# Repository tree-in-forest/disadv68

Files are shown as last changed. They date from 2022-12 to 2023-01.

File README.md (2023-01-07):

# Disadv68 keyboard

This keyboard is a fork of [dactyl-cc](https://github.com/adereth/dactyl-keyboard).

The prototype:
kb_left

Differences with *dactyl-cc* and some notes:

- Fixed switch hole sizes (if you print the current version of *dactly-cc*, you will have a bad time).
- Fixed screw hole sizes for M3 screws and "threaded brass insert" ([AliExpress](https://www.aliexpress.com/item/1005004870993068.htm)).
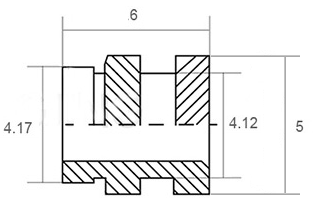
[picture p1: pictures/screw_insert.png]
nut
    

- Original [Kinesis Contoured](https://deskthority.net/wiki/Kinesis_Contoured) keycaps are from ABS and are very expensive (50EUR + shipping).
  *Solution* (use OEM and DSA keycaps). Due to different naming conventions for numbering rows, we will define them as
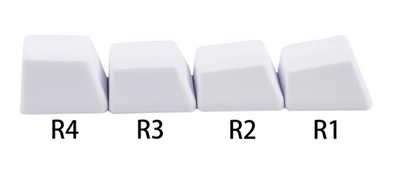
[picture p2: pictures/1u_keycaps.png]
1u
    

  Here is a list of which keycaps you will need (ABS for < 10EUR, PBT < 20EUR):
  - 18 pcs of `1x1u` OEM `R1` (`ZXCV` row),
  - 2  pcs of `2x1u` vertical OEM `R1` (≡ `Numpad Enter` keycap),
  - 2  pcs of `1x2u` horizontal OEM `R1` (≡ `Numpad 0` keycap).
  - 10 pcs of `1x1u` OEM `R2` (`ASDF` row),
  - 12 pcs of `1x1u` OEM `R3` (`QWER` row),
  - 12 pcs of `1x1u` OEM `R4` (`1234` row),
  - 4  pcs of `1x1u` OEM `R5` (`F1F2F3F4` row),
  - 8  pcs of `1x1u` DSA with the deep dish ("blind" keycaps) — you can replace DSA keycaps with `1x1u` OEM `R2` keycaps.
  
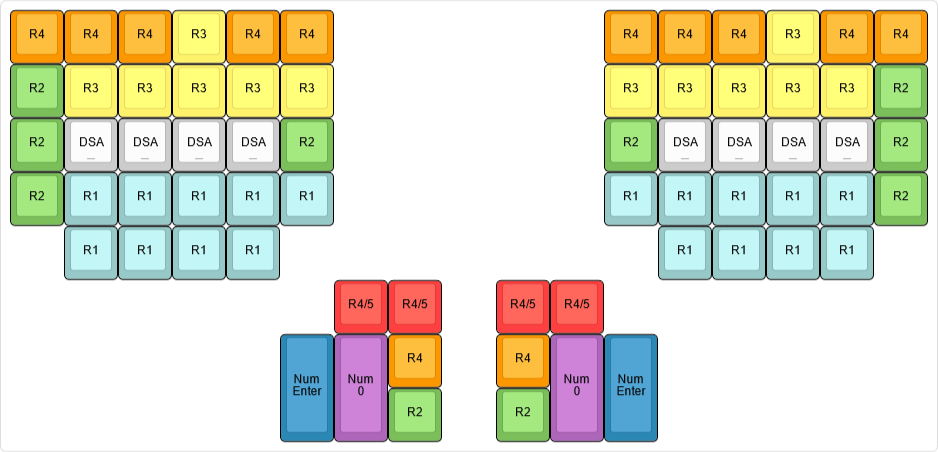
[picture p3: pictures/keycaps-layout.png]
keycaps
  

  The `1u` OEM `R5` keycaps are very rare, so we opted for `R4` keycaps instead. To compensate keycap height difference, we raised the switch sockets/holes by 3mm.
  The `1x1.25u` OEM `R2`s are also very rare so we opted out for `1u` keycaps.
  Note that Cherry stems are not "fully symmetric", therefore if you want to rotate the keycap by 90°, you also need to rotate the switch:

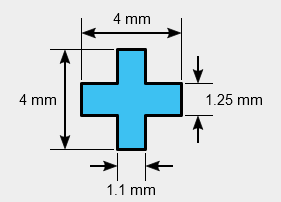
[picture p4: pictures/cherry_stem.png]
stem
  
  
  Sometimes `Numpad Enter` keycaps have rotated stems (therefore, on the standard keyboard the key switch will be placed sideways). Consult with your keycaps vendor if this is the case (it was in ours). This is important because switch sockets have side nubs.
  The current version of the keyboard hull has both sockets with `Numpad Enter` and `Numpad 0` keycaps rotated.

  The other option is to 3D print keycaps. We were unsuccessful in FDM printing — it is hard to get the keycap stems right. Probably the best option is to use [stereolithography](https://en.wikipedia.org/wiki/Stereolithography). If you want to generate the 3D models we suggest you look at the [Parametric Mechanical Keycap Library](https://github.com/rsheldiii/KeyV2).

## FDM printing settings

- Machine Type: Creator 3 Pro
- Material: ASA
- Layer Height: 0.1mm
- Shell Count: 3
- Fill Density: 25%
- Fill Pattern: Hexagon
- Print Speed: 50mm/s
- Travel Speed: 80mm/s
- Extruder Temperature: 250°C
- Platform Temperature: 110°C
- First layer: 0.3mm
- Raft: yes

Due to the long printing time — 50 hours for each side and the small nozzle size, it is very likely that the extruder will get clogged.

## Building STL files

1. Apply your modification to the code. Here are the labels of the key sockets used in the code:
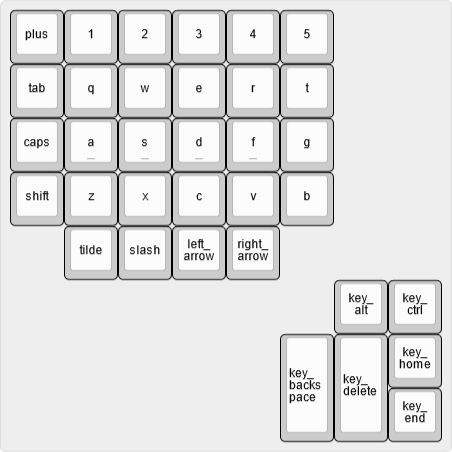
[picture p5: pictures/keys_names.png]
keys_names
   

2. Compile ("requires" CMake).

    ```bash
    cd build
    ./build.sh
    ```

3. Install [OpenSCAD](https://openscad.org/downloads.html) (*Development Snapshot* is the best choice). Files `.scad` will be generated in the folder `build`.

4. Generate STL files.

For measuring distances on STL files we recommend [Blender](https://www.blender.org/).
For post-processing and quick edits, we recommend [Thinkercad](https://www.tinkercad.com).

## Assembly and firmware

Our choice for the microcontroller is `WeAct BlackPill STM32F411CEU6`:

- [QMK docs on blacpill](https://docs.qmk.fm/#/platformdev_blackpill_f4x1?id=weact-blackpill-stm32f4x1)
- [WeAct Studio's blackpill repository](https://github.com/WeActStudio/WeActStudio.MiniSTM32F4x1)

In the folder `things` you can find some custom STLs:

- Custom bottom plate with recesses for USB cable and 12-wire ribbon cable, and modified holes for M3 flat/countersunk head screws.

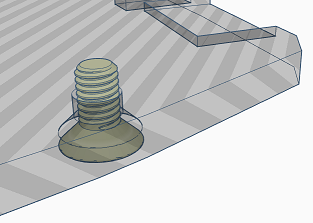
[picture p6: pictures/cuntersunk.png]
screw_hole
  

- A case for blackpill microcontroller.
  
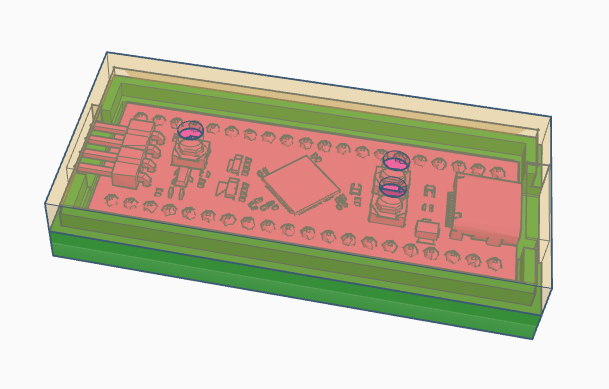
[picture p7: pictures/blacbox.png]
box
  

Note. With low RPM you can easily drill into ASA material.

### What do you need

- 2m of an old hard UTP cable (0 EUR)
- an old floppy drive ribbon cable (or any other ribbon cable, 0EUR)
- 10 pcs of 6mm M3 flat/countersunk/Philips head screws (0.5EUR)
- 10 pcs threaded brass insert (1EUR from Aliexpress)
- keycaps (<10EUR for ABS, <20EUR for PBT on Aliexress — contact the store)
- 68 pcs cherry-like key switches. We have bought 110 Gateron Pro Yellow V2 2.0 for 18EUR (good build quality, linear, pre-lubed).
- WeAct BlackPill STM32F411CEU6 ([where to buy](https://github.com/WeActStudio/WeActStudio.MiniSTM32F4x1#legitimate-purchase-links-as-well-as-pirated-links) 7EUR)
- 24-pin female header for the microcontroller
- 100 1N4148 diodes (0.75EUR)
- Soldering iron with adjustable temperature (borrow, otherwise We recommend [PINEICL](https://pine64.com/product/pinecil-smart-mini-portable-soldering-iron/) or a cheap one on Aliexpress)
- Solder
- Tweezers with a tiny head
- Wirecutter
- Razor knife
- Scissors pliers for wire stripping (that support small wires)
- USB-C cable
- Multimeter
- Hot glue gun
- Around 25 hours of spare time
- ...

### Assembly

1. Clean up/remove support from the printed hull.
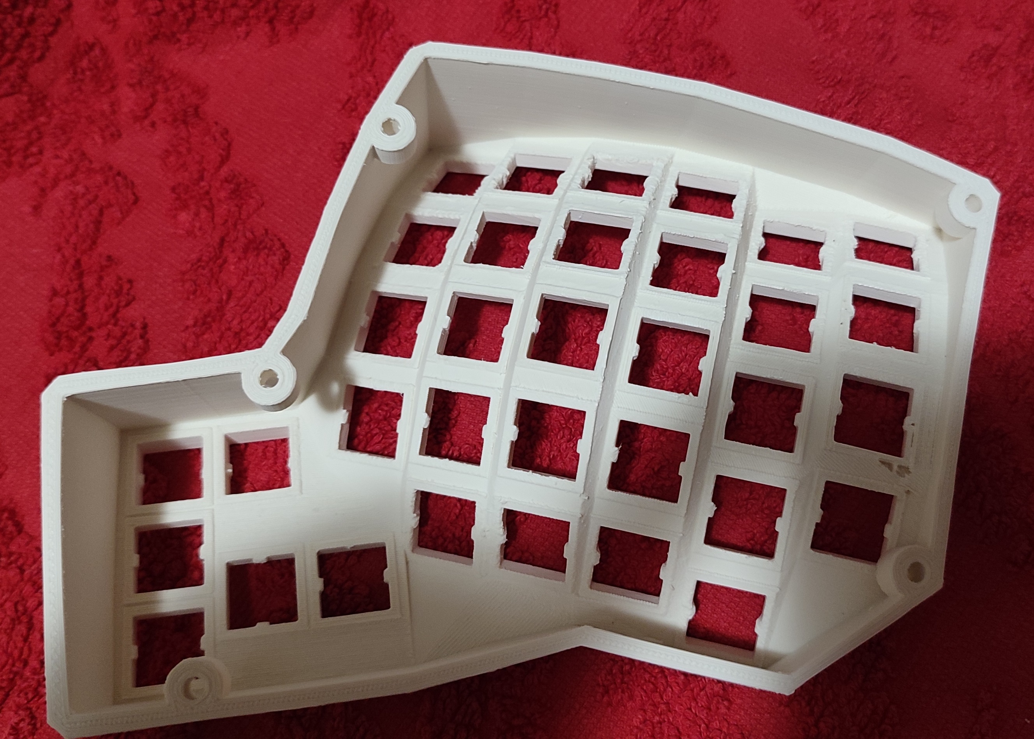
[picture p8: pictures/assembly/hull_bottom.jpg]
hull1
   
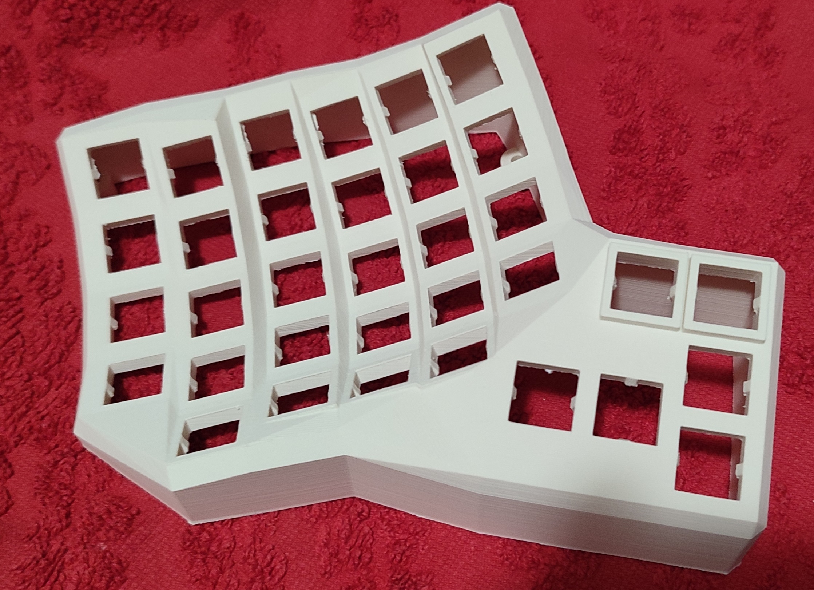
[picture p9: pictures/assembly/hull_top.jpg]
hull2
   

2. Add switches and keycaps
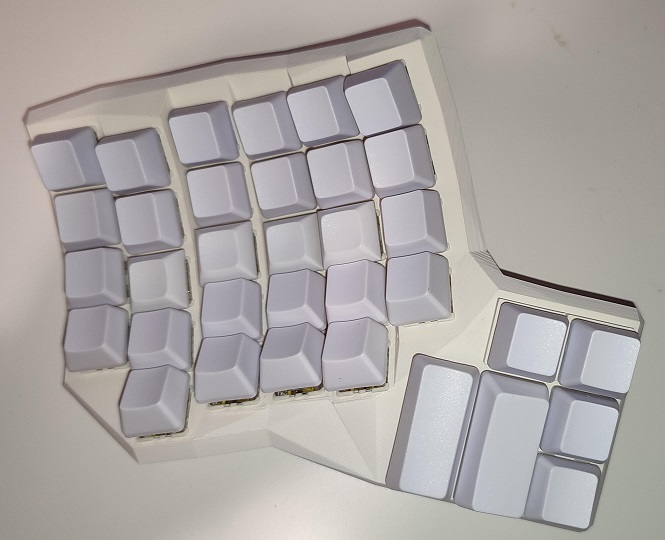
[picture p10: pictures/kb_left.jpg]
left
   

3. Stabilize switches with hot glue.

4. Place wires for the columns (if you start with rows first, it is harder to replace diodes/switches later).

     - Extract/unwind wires from the UTP cable
     - Make a hook.
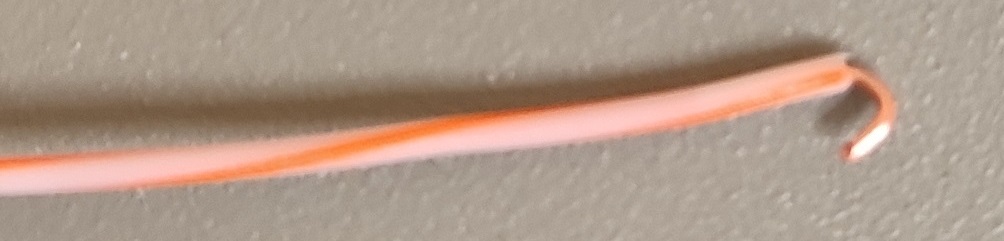
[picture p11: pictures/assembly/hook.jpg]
hook
        
     - Hook up the wire to the top row pin and mark the position for the rest of the pins.
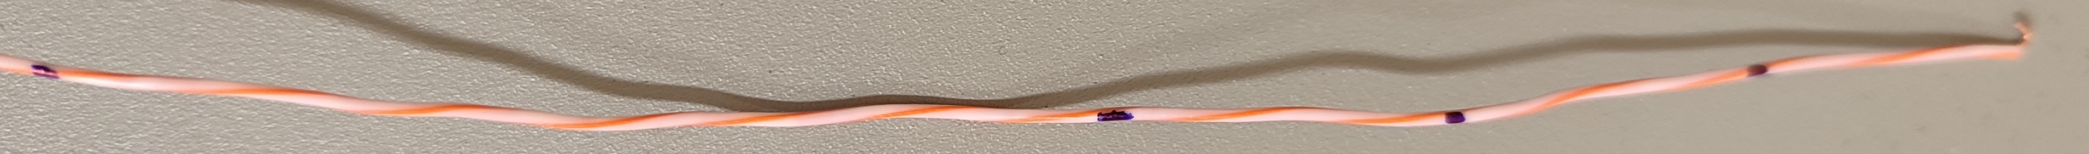
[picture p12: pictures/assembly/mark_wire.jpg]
marks
       
     - Using the scissors pliers for wire stripping cut the insulator for each mark twice. Then use a Razor knife to partially peel off the insulator.
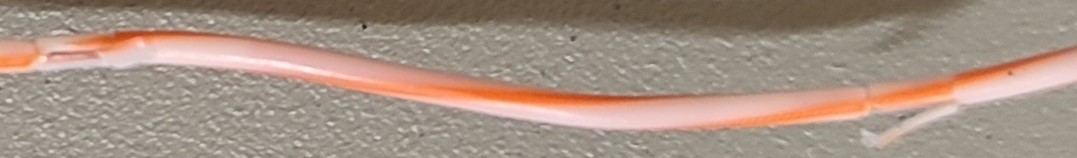
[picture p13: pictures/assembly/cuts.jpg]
cuts
     
     - Remove the rest of the insulator using tweezers.
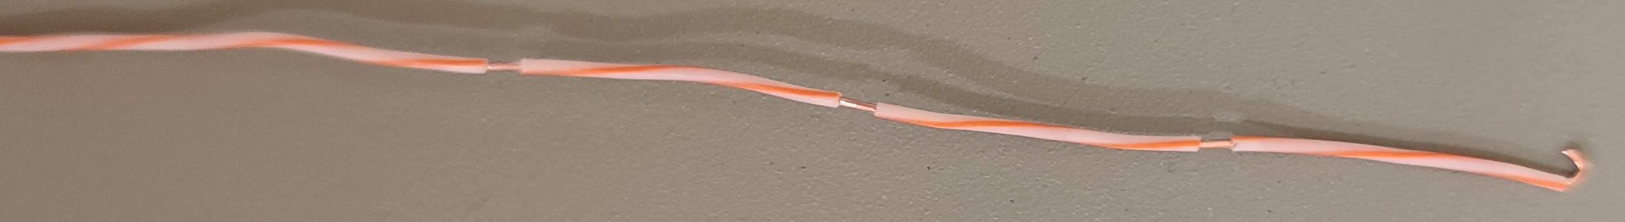
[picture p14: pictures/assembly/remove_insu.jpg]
remove
     
     - Apply flux and solder the column wires to the switch pins.
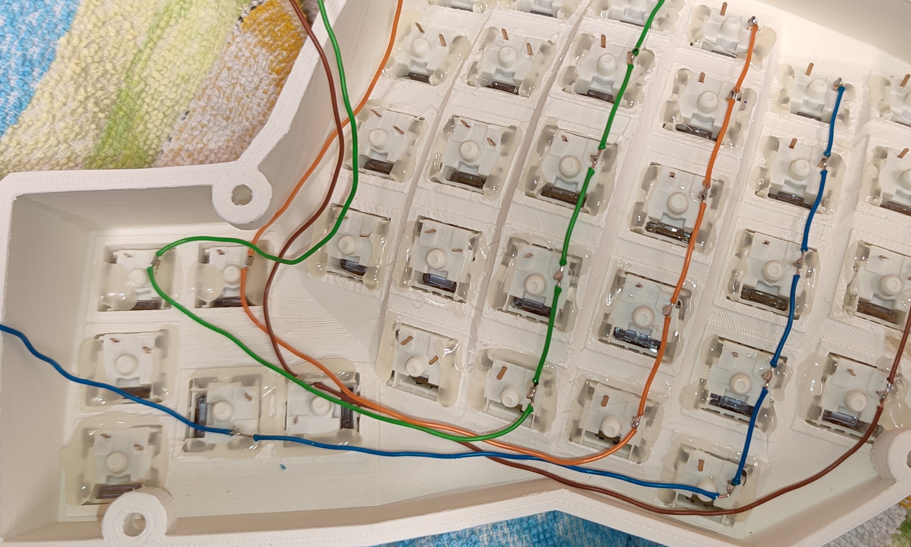
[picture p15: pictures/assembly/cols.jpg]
cols
     

5. Make rows from diodes (start with making "eyes") — double-check the orientation of diodes.
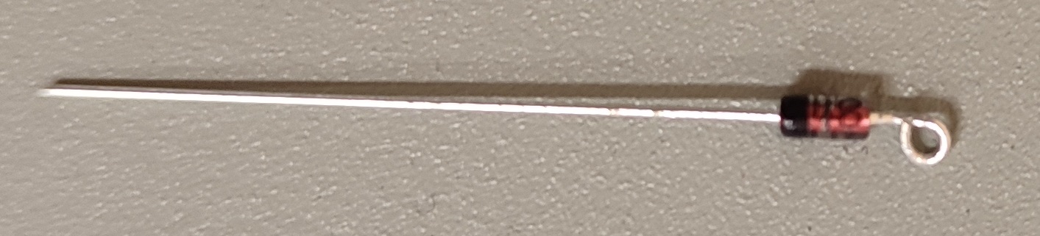
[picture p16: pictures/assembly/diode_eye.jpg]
eye
     
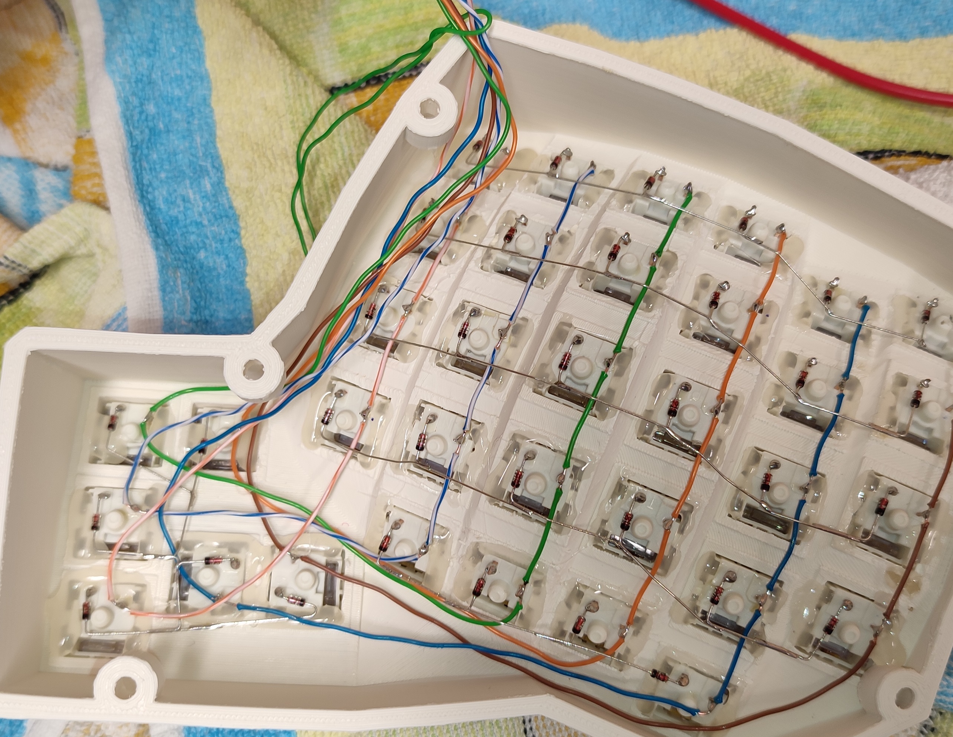
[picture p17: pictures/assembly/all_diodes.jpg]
all_diodes
     

6. Connect wires to the female header for the microcontroller.
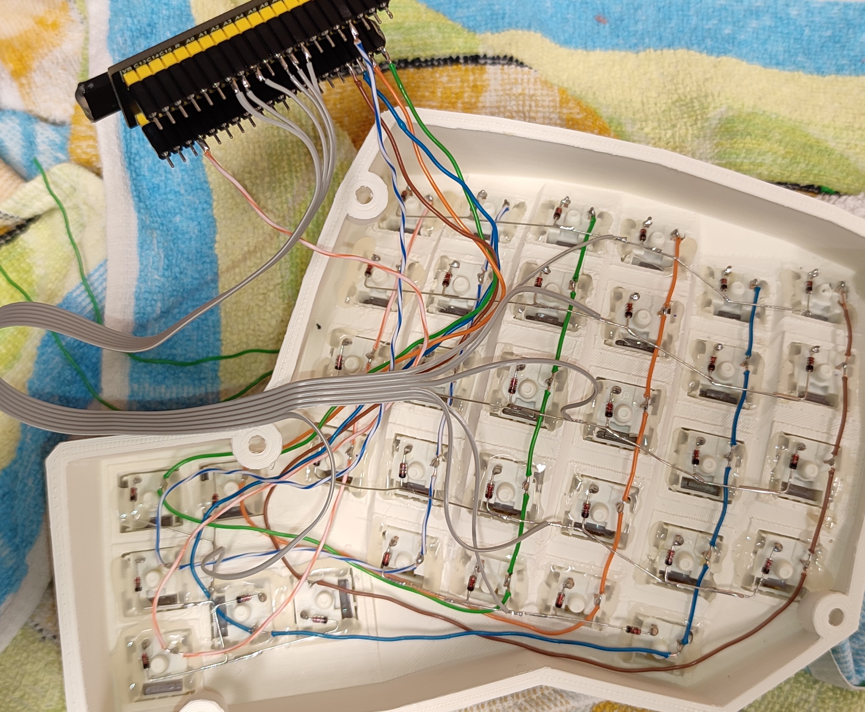
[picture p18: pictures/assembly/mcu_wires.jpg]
mcu_wires
  

7. Test the left side of the keyboard (flash the microcontroller first).
8. Make the right side.
9. Insert screw inserts slowly using soldering iron at 200°C.
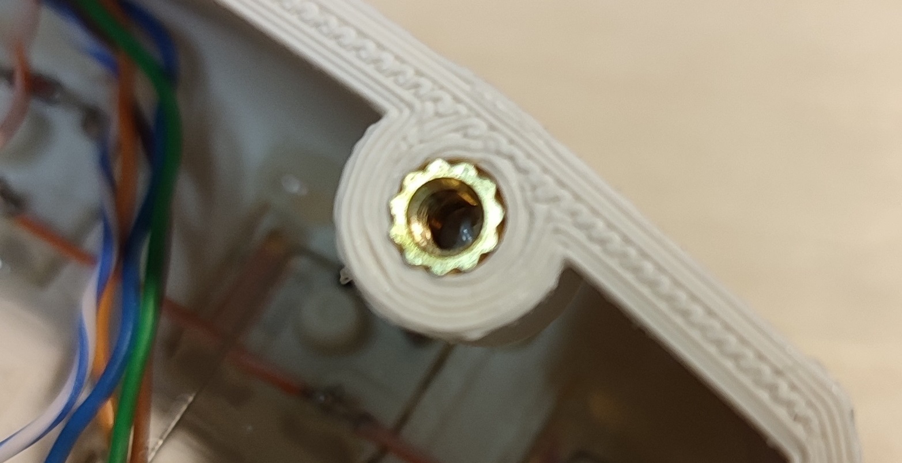
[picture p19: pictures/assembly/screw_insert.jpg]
screw_inserts
  
10. Connect the left and the right side with a 12-wire ribbon (6 columns and 6 rows) cable according to your firmware settings.
11. Connect [USB wires](https://en.wikipedia.org/wiki/USB_hardware) to the female header for the microcontroller (`D-` → `A11`, `D+` → `A12`, `+5V` → `5V`, and `GND` → `G`). This will reduce the footprint of the microcontroller inside the keyboard hull.
12. Secure the wires with hot glue.
13. Make the bottom plates. Our 3D printer had problems. So we used 4mm plywood with longer (8mm) M3 screws. Here is the design for the wooden bottom plate — [bottom_left](things/custom_bottom_plate/bottom_left.svg) and [bottom_right](things/custom_bottom_plate/bottom_right.svg). These designs do not take into account the ASA shrinkages. You need to do modifications on your own.
14. Use M3 screws to secure the bottom plates
15. Add pads to the bottom plates (you can make them from an old mousepad).
16. Walla, you should have a functional keyboard now.
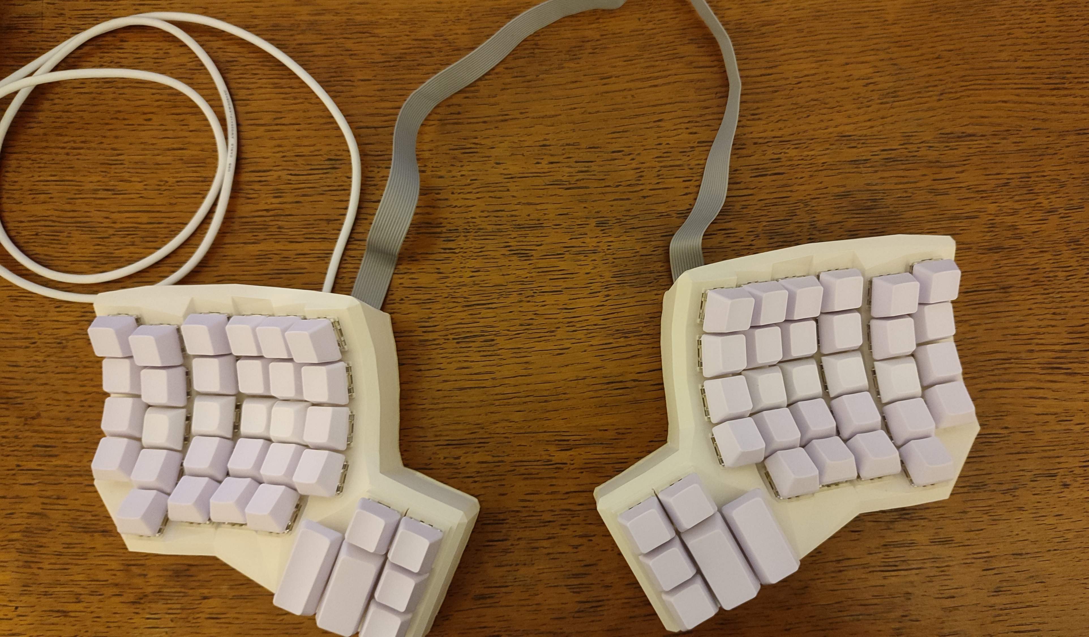
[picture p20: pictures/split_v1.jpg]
v1
   

### Firmware

...can be found [here — qmk_firmware](https://github.com/tree-in-forest/qmk_firmware/tree/disadv68/keyboards/handwired/disadv68).

### Layout

The default layout is:

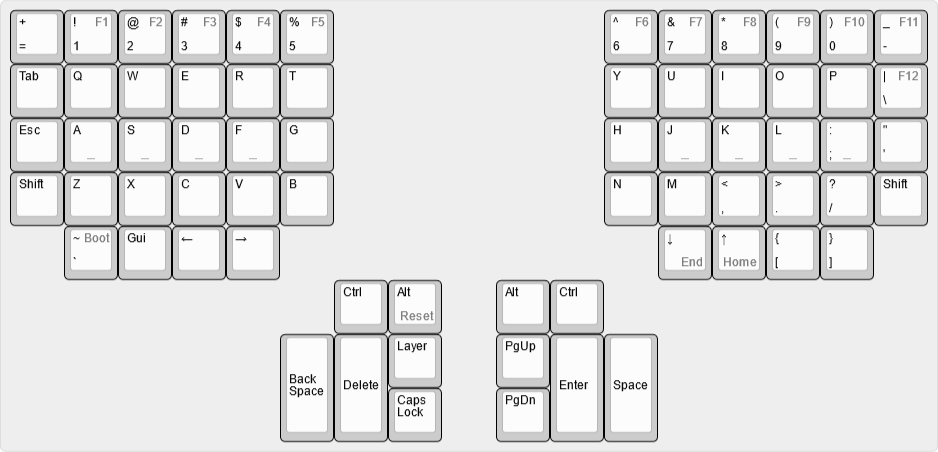
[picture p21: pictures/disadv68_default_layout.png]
default_layout


- To access F-keys use the Layer key.
- Reset the keyboard: `Layer + RAlt`
- Jump to the bootloader ``Layer + ` ``

Nice layouts to check out:

- [The Hands Down™ Layout](https://sites.google.com/alanreiser.com/handsdown)

## Traveling case

Coming soon.

## Wrist rests

Coming soon.

## Adjustable tilting supports

Coming soon.

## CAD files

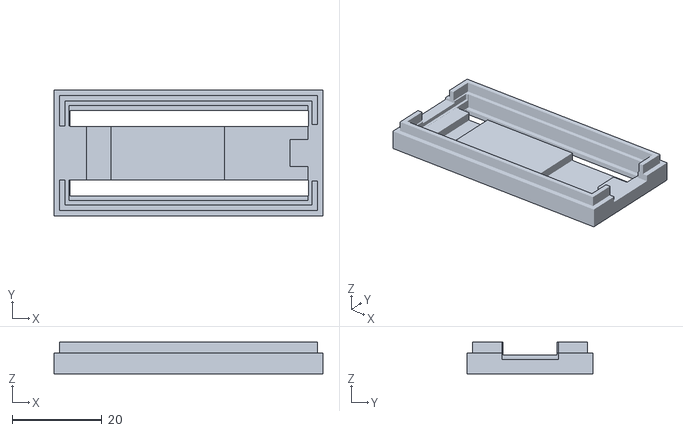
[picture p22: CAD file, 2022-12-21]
things/blacbox/blackbox_bottom.stl
60.0 x 28.0 x 7.10

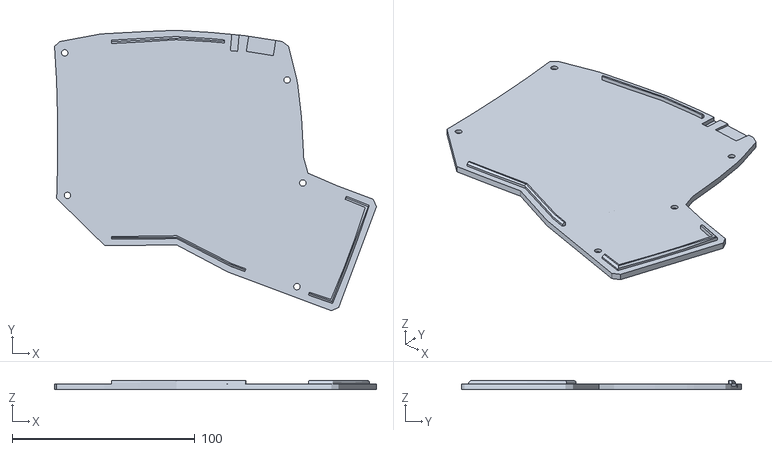
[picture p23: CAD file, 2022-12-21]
things/custom_bottom_plate/custom_bottom_plate_left.stl
176.2 x 153.4 x 5.00

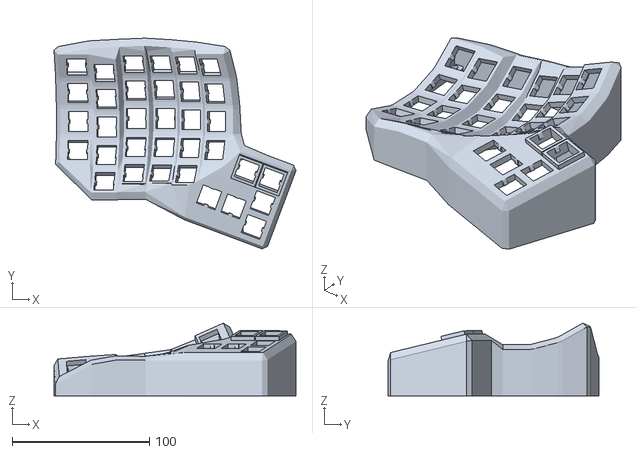
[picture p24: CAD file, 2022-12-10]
things/left.stl
176.2 x 153.4 x 53.0

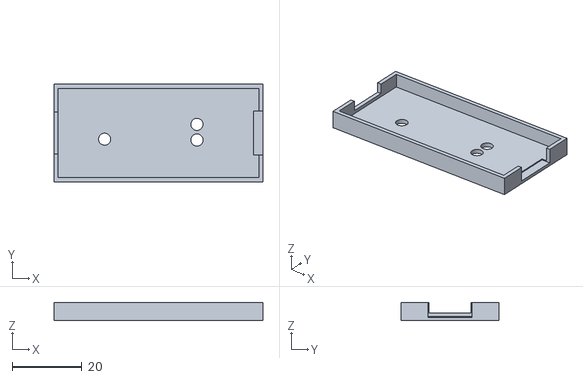
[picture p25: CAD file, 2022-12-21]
things/blacbox/blackbox_top.stl
60.0 x 28.0 x 5.20

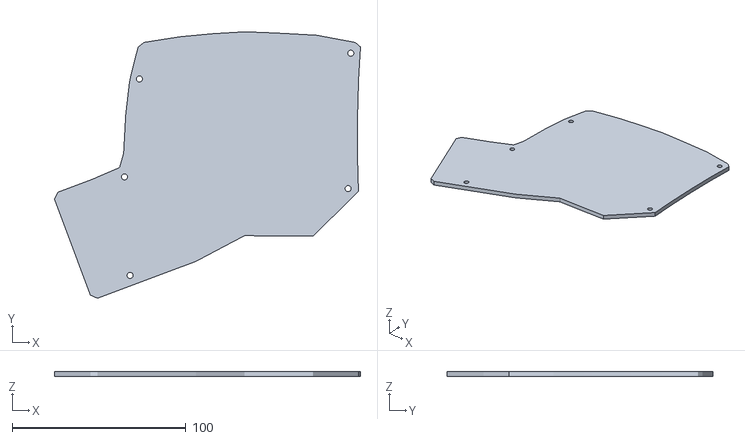
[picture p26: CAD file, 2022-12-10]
things/bottom_right.stl
176.2 x 153.4 x 3.00

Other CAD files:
things/custom_bottom_plate/custom_bottom_plate_right.stl
things/bottom_left.stl
things/right.stl

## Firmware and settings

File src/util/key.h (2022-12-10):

#pragma once

#include <functional>
#include <glm/glm.hpp>
#include <memory>
#include <string>

#include "scad.h"
#include "transform.h"

namespace scad {

// All sizes in mm.
const double kSwitchWidth = 14.4;
const double kSwitchThickness = 4;
const double kWallWidth = 2;

const double kDsaHeight = 8;
const double kSaHeight = 12.5;
// This is the height of the taller side on the key. The short side has kSaHeight.
const double kSaEdgeHeight = 13.7;
const double kDsaTopSize = 13.2;     // 0.5 * kMmPerInch;
const double kDsaBottomSize = 18.4;  // 0.725 * kMmPerInch;
// The size half way up the key used to generate the cap shape.
const double kDsaHalfSize = 16.2;
const double kSaHalfSize = 17.2;

// Size for the tall sa edged key.
const double kSaTallHeight = 14;
const double kSaTallEdgeHeight = 16.5;

const double kSwitchHorizontalOffset = kSwitchWidth / 2 + kWallWidth;

// This is the distance between the top of the switch plate and the tip of the switch stem.
const double kSwitchTipOffset = 10;

enum class KeyType {
  DSA,
  SA,            // Row 3
  SA_EDGE,       // Row 2
  SA_TALL_EDGE,  // Row 1
};
// For SA edge variants. Which side of the key the edge should be rendered.
enum class SaEdgeType { LEFT, RIGHT, TOP, BOTTOM };

struct Key {
 public:
  Key() {
  }

  Key(double x, double y, double z) {
    t().x = x;
    t().y = y;
    t().z = z;
  }

  // A name for debugging purposes. Can also be used to determine the names for key specific output
  // files.
  std::string name;

  TransformList parent_transforms;
  TransformList local_transforms;

  // These add extra width to the switch and offset the locations of the corners (GetTopLeft etc).
  double extra_width_top = 0;
  double extra_width_bottom = 0;
  double extra_width_left = 0;
  double extra_width_right = 0;

  // This makes the switch taller (moves the corner connectors down and increases wall height) while
  // leaving the top plate of the switch at the same point.
  double extra_z = 0;

  bool add_side_nub = true;
  bool disable_switch_z_offset = false;

  KeyType type = KeyType::DSA;
  SaEdgeType sa_edge_type = SaEdgeType::BOTTOM;

  void Configure(std::function<void(Key& k)> fn) {
    fn(*this);
  }

  Key& SetPosition(double x, double y, double z);
  Key& SetParent(const Key& key);
  Key& SetParent(const TransformList& transforms);

  Transform& t() {
    return local_transforms.mutable_front();
  }

  Transform& AddTransform() {
    return local_transforms.AddTransformFront();
  }

  TransformList GetTransforms() const;
  TransformList GetSwitchTransforms() const;

  Shape GetSwitch(bool rotated = false, double rised = 0.0) const;
  Shape GetInverseSwitch() const;
  // Used to subtract and clear space in the key cap's path. Vertical length can be explicitly
  // passed to support cutting out for long keys like enter on the kinesis.
  Shape GetInverseCap(double custom_vertical_length = -1) const;
  Shape GetCap(bool fill_in_cap_path = false) const;

  // This is the outermost conner of the switch. You can specify an offset to scale the point back
  // by the specified x,y amount towards the center of the switch. If you had a centered 2x2 post
  // and you wanted the corner to line up with outmost point of the switch, you could specify an
  // offset of -1.
  TransformList GetTopRight(double offset = 0) const;
  TransformList GetTopLeft(double offset = 0) const;
  TransformList GetBottomRight(double offset = 0) const;
  TransformList GetBottomLeft(double offset = 0) const;
  // The same as GetSwitchTransforms but with a more clear name if you are intending to find the
  // middle point.
  TransformList GetMiddle() const;

  // Corners clockwise starting at top left. Will have size 4.
  std::vector<TransformList> GetCorners(double offset = 0) const;

 private:
  // These are the inner corners of the switch plate.
  TransformList GetTopRightInternal() const;
  TransformList GetTopLeftInternal() const;
  TransformList GetBottomRightInternal() const;
  TransformList GetBottomLeftInternal() const;
};

struct KeyGrid {
  explicit KeyGrid(std::vector<std::vector<Key*>> data) : data(std::move(data)) {
  }

  std::vector<Key*> column(int c) {
    std::vector<Key*> result;
    for (auto& row : data) {
      result.push_back(row[c]);
    }
    return result;
  }

  std::vector<Key*> row(int r) {
    return data[r];
  }

  Key* get_key(int row, int column) {
    if (row < 0 || row >= num_rows()) {
      return nullptr;
    }
    auto& r = data[row];
    if (column < 0 || column >= r.size()) {
      return nullptr;
    }
    return r[column];
  }

  std::vector<Key*> keys() {
    std::vector<Key*> result;
    for (auto& row : data) {
      for (Key* key : row) {
        if (key) {
          result.push_back(key);
        }
      }
    }
    return result;
  }

  size_t num_columns() {
    return data[0].size();
  }

  size_t num_rows() {
    return data.size();
  }

  std::vector<std::vector<Key*>> data;
};

// Used to connect key corners together. It is thin so it can have width issues when the two
// connectors being hulled don't have a large projection on one another. (keys close together with
// vertical separation)
Shape GetPostConnector();

Shape ConnectVertical(const Key& top,
                      const Key& bottom,
                      Shape connector = GetPostConnector(),
                      double offset = 0);
Shape ConnectHorizontal(const Key& left,
                        const Key& right,
                        Shape connector = GetPostConnector(),
                        double offset = 0);
Shape ConnectDiagonal(const Key& top_left,
                      const Key& top_right,
                      const Key& bottom_right,
                      const Key& bottom_left,
                      Shape connector = GetPostConnector(),
                      double offset = 0);

Shape Tri(const TransformList& t1,
          const TransformList& t2,
          const TransformList& t3,
          Shape connector = GetPostConnector());
Shape Tri(const Shape& s1, const Shape& s2, const Shape& s3);

Shape TriHull(const TransformList& t1,
              const TransformList& t2,
              const TransformList& t3,
              const TransformList& t4,
              Shape connector = GetPostConnector());
Shape TriHull(const Shape& s1, const Shape& s2, const Shape& s3, const Shape& s4);

Shape TriFan(const TransformList& center,
             const std::vector<TransformList>& transforms,
             Shape connector = GetPostConnector());
Shape TriFan(Shape center, const std::vector<Shape>& shapes);

// Makes a triangle with every consecutive set of 3 transforms. TriHull would be the same as
// calling this with 4 transforms.
Shape TriMesh(const std::vector<TransformList>& transforms, Shape connector = GetPostConnector());
Shape TriMesh(const std::vector<Shape>& shapes);
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

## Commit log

2022-12-10 Fixed switch hole sizes
    [bottom_left.stl, bottom_right.stl, left.stl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]
2022-12-10 rotated/raised keys, list of keycaps
    [bottom_left.stl, bottom_right.stl, left.stl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]
2022-12-21 partial assembly instrutions
    [blackbox_bottom.stl, blackbox_top.stl, custom_bottom_plate_left.stl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]
